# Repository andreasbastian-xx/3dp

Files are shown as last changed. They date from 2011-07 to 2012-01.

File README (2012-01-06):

arduino/ contains firmware for the 3D printer.

autoCAD/ contains a variety of 3D models.

Datasheets and ref/ contains several datasheets and reference material for parts used in the project.

Final Report/ contains the final report that I wrote about the project.

test_files/ contains GCode generated by replicatorG and .stl models.

This project was funded by the Halpern Family Engineering Design Fund during the summer of 2011 at the Swarthmore College Department of Engineering.  

Please feel free to download and use any files or code from this project, though the modified firmware is highly customized.  Also, please feel free to contact me with questions or for any other reason at andy(at)andreasbastian.com.

Andreas Bastian 2012

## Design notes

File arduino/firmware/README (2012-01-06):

in_use/ contains the successfully modified Ultimaker Arduino firmware.

old_code/ contains abandoned and dissected firmware files that I used to probe and explore the firmware.  

Andreas Bastian 2012

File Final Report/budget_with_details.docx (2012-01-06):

Item: | Cost: | Use in the Project:
Aluminum angle stock | $30 | Used in a machined bracket to join two flatbed scanners to build a 2D translation system. This prototype translation system was abandoned for a simpler and more reliable system.
Steel drill rod | $15 | Used as gantry material in both prototype translation systems.
Linear bearings | $120 | Intended for use in the first prototype translation system and were not used in the second prototype translation system.
Stepper drivers | $100 | Five A4983 stepper drivers were purchased to supply power to the various stepper motors that actuate the hardware.
Arduino Microcontroller | $64 | Used to control all motors and sensors in the system and manage communication with the computer.
Photointerrupters | $15 | Used to check positioning of the 2D translation system.
Lasers | $198 | Two fiber-coupled infrared lasers were purchased used.
Brake cable | $15 | The cable was used to actuate the laser shuttering mechanism.
MDF | $10 | Chief construction material of the prototype system.
5kgs Candelilla wax powder | $95 | Main component of the print powder.
Sieves | $110 | Used for mixing, refining, and reclaiming the print powder.
Total Project Cost: | $772 | All materials purchased for the project.
Total Prototype Cost: | $413 | Materials used in the final prototype system.

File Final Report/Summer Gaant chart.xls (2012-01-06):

Tasks | 5/29 - 6/4 | 6/5 - 6/11 | 6/12 - 6/18 | 6/18 - 6/25 | 6/26 - 7/2 | 7/3 - 7/9 | 7/10 - 7/16 | 7/17 - 7/23 | 7/24 - 7/30 | 7/31 - 8/6
1). X-Y Translation System
a). Research, design, and purchase materials
b). Fabrication
2). Laser Optics
a). Research and design mounts and optics options
b). Install laser and optics on X-Y translator
c). Laser characterization studies
3). Powder Bed and Reservoir
a). Research, design, and purchase materials
b). Fabricate and test
4). Powder Distributor
a). Research, design, and purchase materials
b). Fabricate and install on powder bed
5). Software
a). Write and distribute software design survey
b). Work on user interface

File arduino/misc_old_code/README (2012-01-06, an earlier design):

This directory contains a variety of small programs used in testing and calibration as well as abandoned DIY serial communication code.

Andreas Bastian 2012

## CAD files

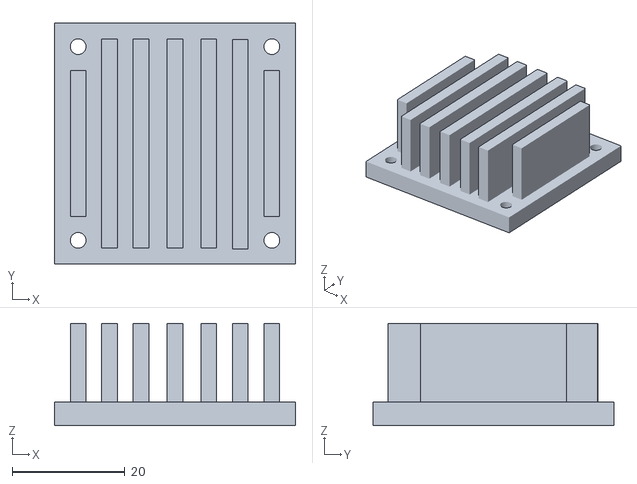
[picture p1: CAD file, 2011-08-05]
autoCAD models/stepper_heatsink_single.stl
42.7 x 42.7 x 18.2

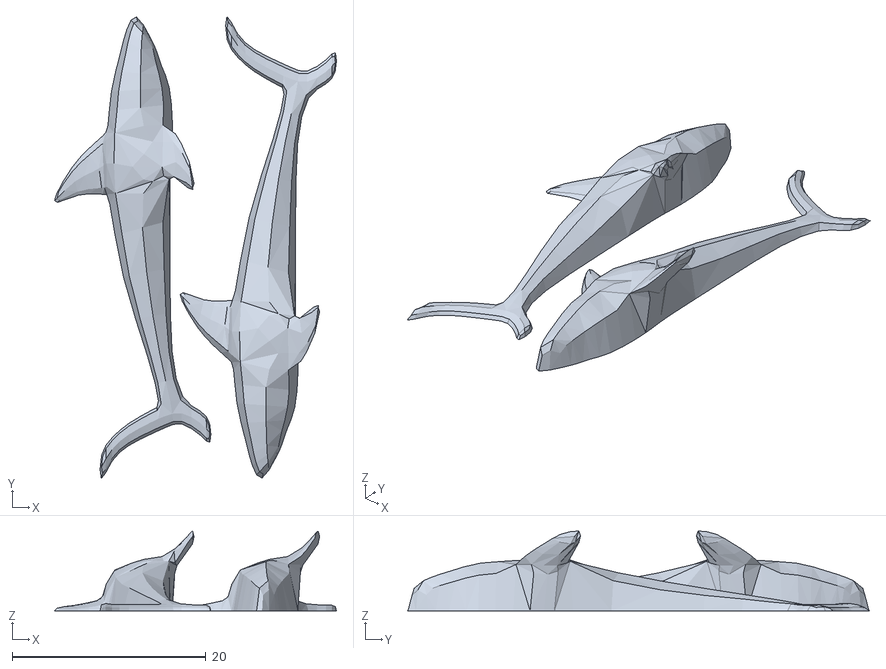
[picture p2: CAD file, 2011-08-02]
test_files/2-3inch_shark.stl
29.1 x 47.7 x 8.24

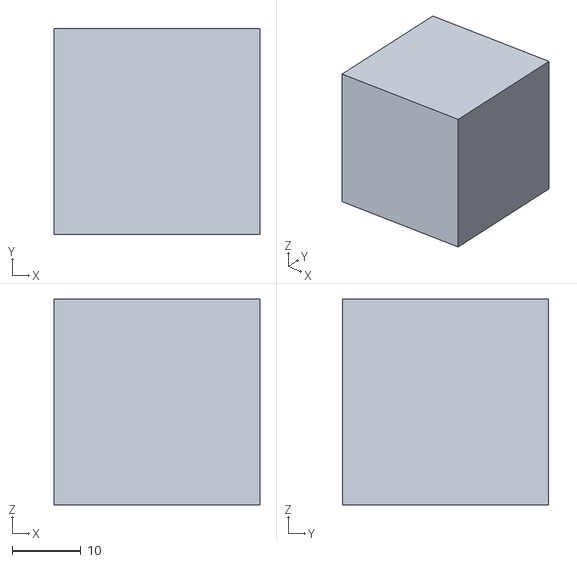
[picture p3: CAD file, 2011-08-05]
test_files/thingiverse/40mmcube.stl
30.0 x 30.0 x 30.0

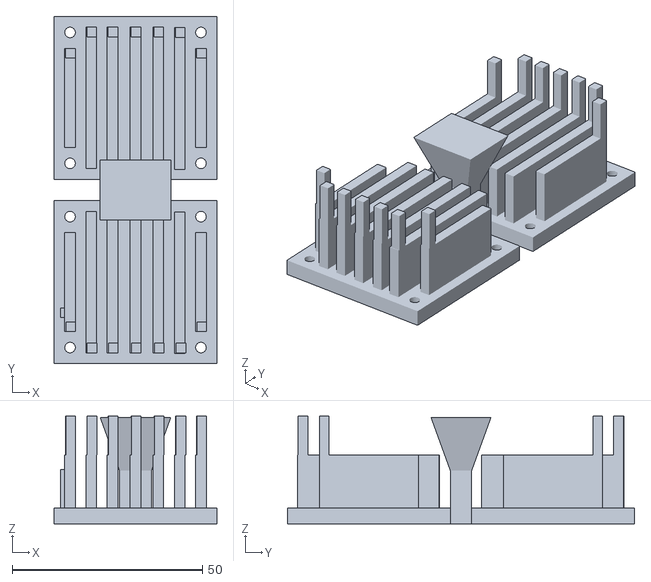
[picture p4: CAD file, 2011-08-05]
autoCAD models/stepper_heatsink.stl
42.7 x 91.1 x 28.3

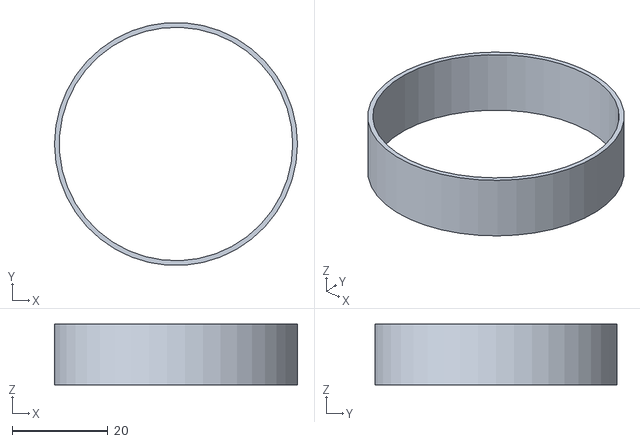
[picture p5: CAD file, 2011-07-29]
test_files/2_inch_circle_scaled.stl
50.8 x 50.7 x 12.7

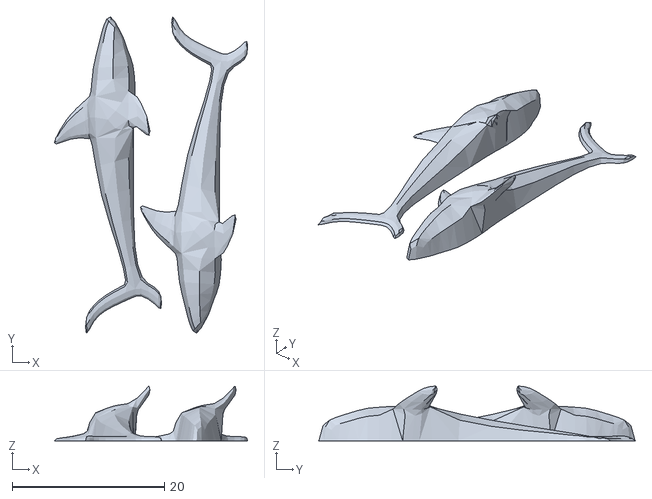
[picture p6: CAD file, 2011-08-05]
test_files/thingiverse/shark-l-r.stl
25.4 x 41.7 x 7.20

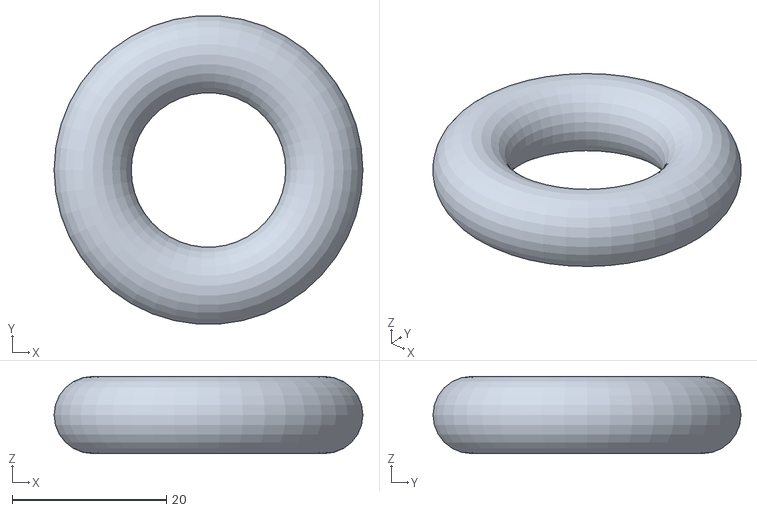
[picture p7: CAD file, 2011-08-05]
autoCAD models/torus.stl
40.0 x 39.9 x 10.00

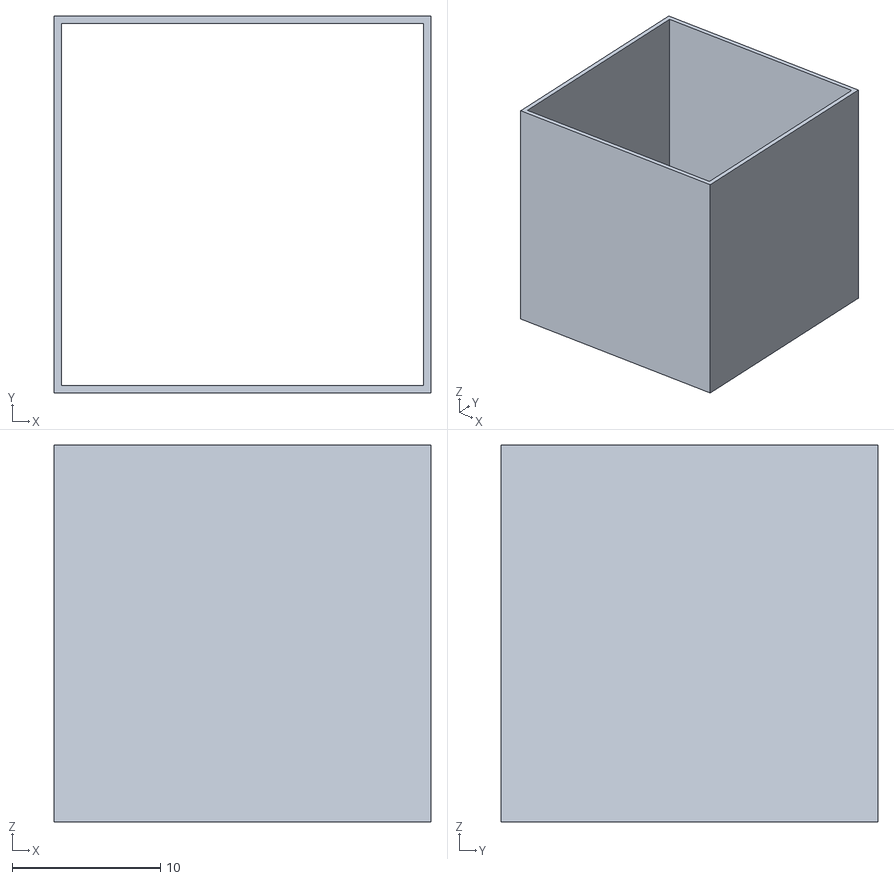
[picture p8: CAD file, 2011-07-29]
test_files/square_tube_fresh.stl
25.4 x 25.4 x 25.4

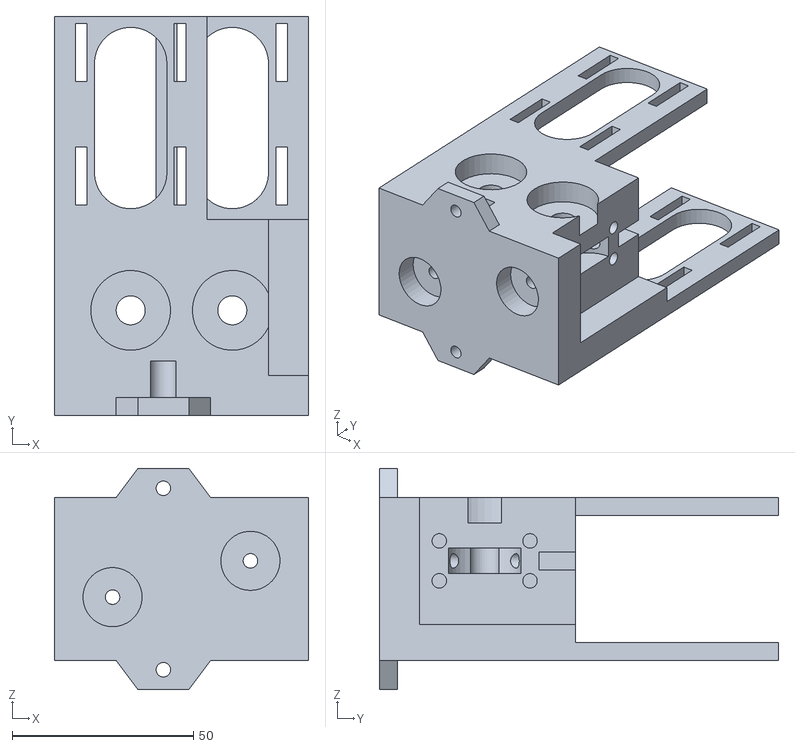
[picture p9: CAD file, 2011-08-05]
test_files/thingiverse/dualextruder.STL
70.0 x 110.0 x 61.0

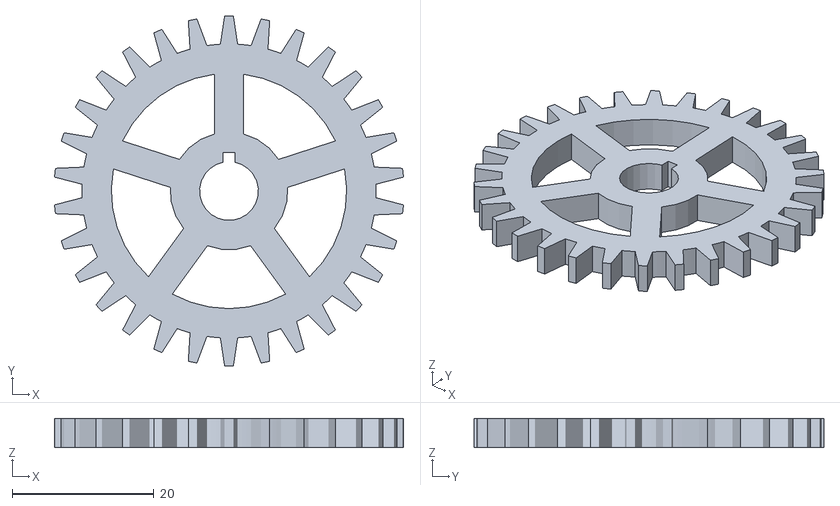
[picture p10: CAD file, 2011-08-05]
autoCAD models/gear.stl
49.2 x 49.4 x 4.15

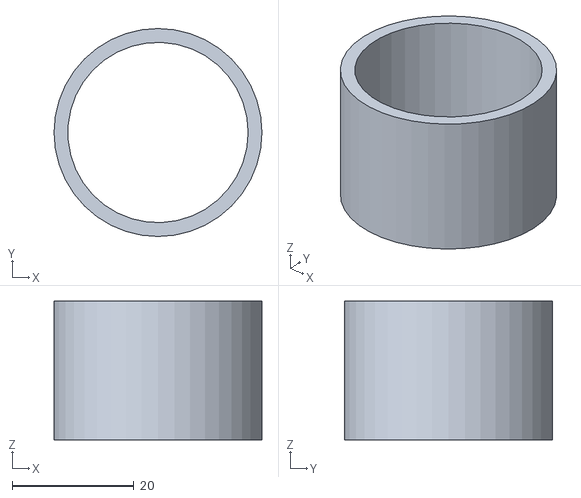
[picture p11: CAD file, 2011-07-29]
test_files/pipe_gcode_raw.stl
34.2 x 34.2 x 22.8

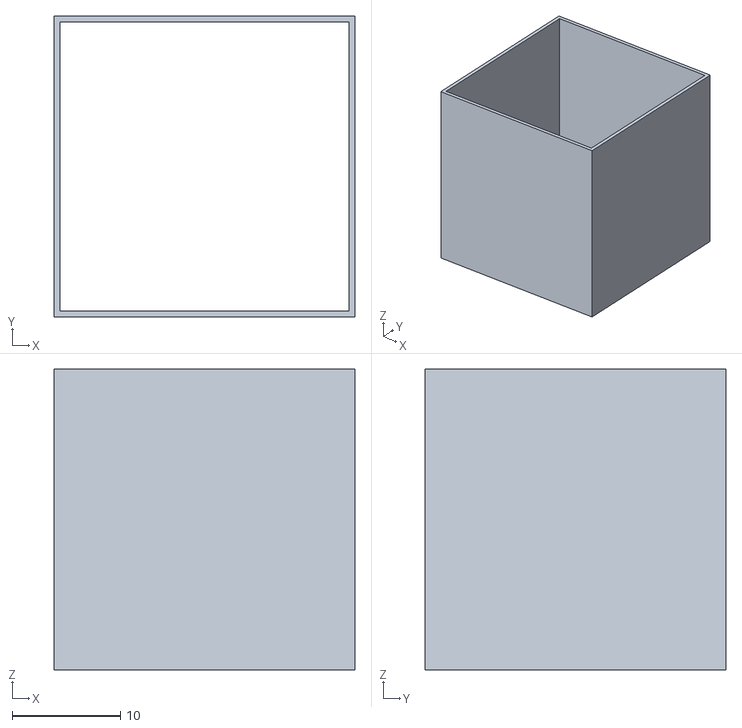
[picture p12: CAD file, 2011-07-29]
test_files/square_pipe.stl
27.8 x 27.8 x 27.8

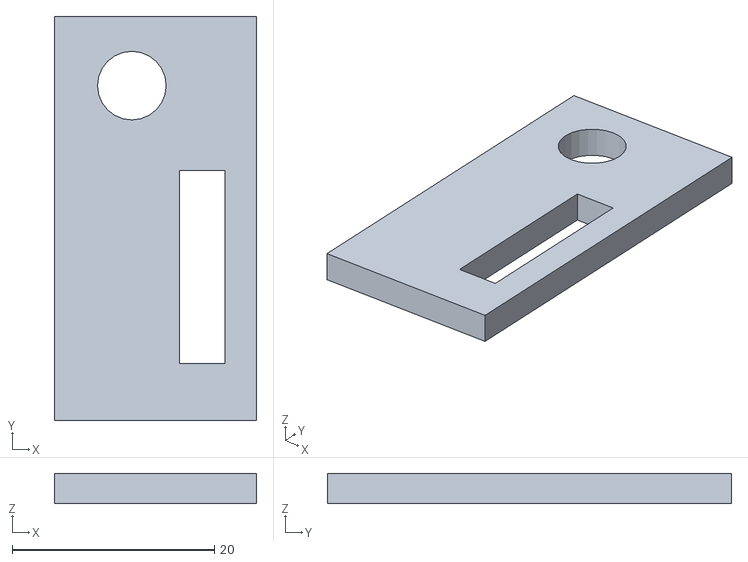
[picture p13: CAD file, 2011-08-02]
autoCAD models/test_block.stl
20.0 x 40.0 x 3.00

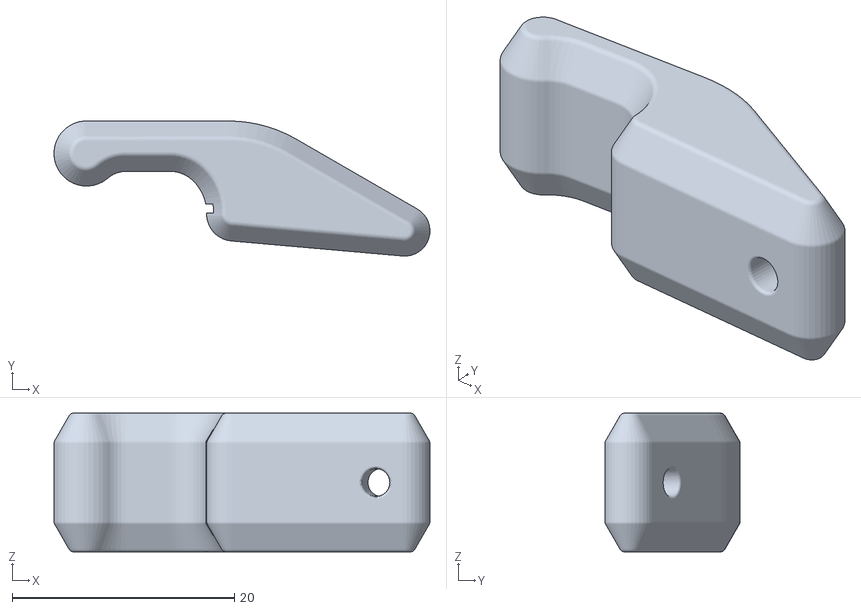
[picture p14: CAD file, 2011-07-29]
test_files/test.stl
33.8 x 12.1 x 12.5

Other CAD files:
autoCAD models/trig_geo_piece.dwg
autoCAD models/1x40x0.5_bar.stl
autoCAD models/2_inch_circle.dwg
autoCAD models/gear.dwg
autoCAD models/stepper_heatsink.dwg
autoCAD models/test_block.dwg
autoCAD models/torus.dwg
test_files/1mmSquare.stl
test_files/pipe.stl

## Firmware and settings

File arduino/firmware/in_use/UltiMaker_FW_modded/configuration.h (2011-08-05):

#ifndef CONFIGURATION_H
#define CONFIGURATION_H

#define VERSION_STRING "ULTIMAKER:BATCH=1,PCB=1.5.3,ATMEGA=2560 FW:V=1.1,BUILD=1 E0:TC597=1,SPEED=14 Z:PITCH=3MM"

/*
 *  This is the configuration file for the RepRap Motherboard microcontroller.
 *  Set values in it to match your RepRap machine.
 *  
 *  Lines in here with a 
 *
 *        // *RO
 *
 *  Comment at the end (read-only) should probably only be changed if you really
 *  know what you are doing...
 */

// Here are the Motherboard codes; set MOTHERBOARD to the right one
// A standard Mendel is MOTHERBOARD 2

// (Arduino: 0 - no longer in use)
// Sanguino or RepRap Motherboard with direct drive extruders: 1
// RepRap Motherboard with RS485 extruders: 2
// Arduino Mega: 3
// Ultimaker users: This should be 3 if your system uses an Arduino Mega, not 1.1 or something that you see on your Ultimaker Electronics.

#define MOTHERBOARD 3 

/*********************************************************************************************
*  _   _ _ _   _                 _
* | | | | | |_(_)_ __ ___   __ _| | _____ _ __
* | | | | | __| | '_ ` _ \ / _` | |/ / _ \ '__|
* | |_| | | |_| | | | | | | (_| |   <  __/ |
*  \___/|_|\__|_|_| |_| |_|\__,_|_|\_\___|_|
* 
* Valid for versions: 1.0 and 1.1
* For documentation, see http://www.ultimaker.com/
*********************************************************************************************/

#if MOTHERBOARD == 3

// Set to 1 if enable pins are inverting
// For RepRap stepper boards version 1.x the enable pins are *not* inverting.
// For RepRap stepper boards version 2.x and above the enable pins are inverting.
#define INVERT_ENABLE_PINS 1

// Set ENDSTOP_PULL_UPS to "true" if you're using microswitches
// This will put a logical high in the input pins by connecting an internal 20K resistor to Vcc.
#define ENDSTOP_PULL_UPS true

// Set to one if the axis opto-sensor outputs inverting (ie: 1 means open, 0 means closed)
// RepRap opto endstops with H21LOI sensors are not inverting; ones with H21LOB
// are inverting.
// Set [XYZ]_ENDSTOP_INVERTING to "true" for using microswitches.

#define X_ENDSTOP_INVERTING true
#define Y_ENDSTOP_INVERTING true
#define Z_ENDSTOP_INVERTING true
#define THRESH 60 //logic threshold for analogRead(LIM_PIN)

// Motherboard 3 driving Pololu microstepping controllers - 16 microsteps

// Axis scaling in stepper-motor steps per mm of movement

// Select 1/16 STEP!
#define X_STEPS_PER_MM   12.322
#define INVERT_X_DIR 0

// Select 1/16 STEP!
#define Y_STEPS_PER_MM   12.424
#define INVERT_Y_DIR 0

// This stepper driver should be in EIGHT STEP MODE (LOW/HIGH/LOW)
#define Z_STEPS_PER_MM   191.86
#define INVERT_Z_DIR 0

//Feed Piston:
#define F_STEPS_PER_MM   91.134
#define INVERT_F_DIR 1

//Wiper stepper:
#define W_STEPS_PER_MM   9.6189 
#define INVERT_Z_DIR 0

// Stepper-driven extruder
// E_STEPS_PER_MM is the number of steps needed to 
// extrude 1mm out of the nozzle.  E0 for extruder 0;
// E1 for extruder 1, and so on.

//#define E0_STEPS_PER_MM   14.0//17.6      // NEMA 17 59/11 geared extruder 8mm diameter drive
//#define E1_STEPS_PER_MM   14.0//17.6      // NEMA 17 59/11 geared extruder 8mm diameter drive

// The temperature routines get called each time the main loop
// has gone round this many times

#define SLOW_CLOCK 2000

// If you want to enable fancy stuff like RGB LEDs for feedback and just to show off.
// Make sure FANCY is defined if you want to have this enabled, otherwise comment it out.
//#define FANCY
//#define FANCY_LCD
// Here you can choose 0.0-1.0 for the power to the LED array.
//#define FANCY_LED_PWM_MULTIPLY 1.0 // in case you run everything at a voltage higher than 12V!

#endif

//**********************************************************************************************

// The speed at which to talk with the host computer; default is 57600

#define HOST_BAUD 57600 // *RO

// Set 1s where you have endstops; 0s where you don't
// Both Darwin and Mendel have MIN endstops, but not MAX ones.

#define ENDSTOPS_MIN_ENABLED 1
#define ENDSTOPS_MAX_ENABLED 1

// The number of mm below which distances are insignificant (one tenth the
// resolution of the machine is the default value).

#define SMALL_DISTANCE 0.01 // *RO

// Useful to have its square

#define SMALL_DISTANCE2 (SMALL_DISTANCE*SMALL_DISTANCE) // *RO

//our maximum feedrates in mm/minute
#define FAST_XY_FEEDRATE 800.0
#define FAST_Z_FEEDRATE  100

// Data for acceleration calculations
// Comment out the next line to turn accelerations off
//#define ACCELERATION_ON
// ERIK: changing to a software configurable parameter:
// To enable acceleration by default, configure to true. It can be turned of with M-code M142
//acceleration_enabled = true;

#define SLOW_XY_FEEDRATE 360 // Speed from which to start accelerating
#define SLOW_Z_FEEDRATE 40

#define W_FEEDRATE 800 //wiper feedrate


#if INVERT_ENABLE_PINS == 1  // *RO
#define ENABLE_ON LOW        // *RO
#else                        // *RO
#define ENABLE_ON HIGH       // *RO
#endif                       // *RO

// Set these to 1 to disable an axis when it's not being used,
// and for the extruder.  Usually only Z is disabled when not in
// use.  You will probably find that disabling the others (i.e.
// powering down the steppers that drive them) when the ends of
// movements are reached causes poor-quality builds.  (Inertia
// causes overshoot if the motors are not left powered up.)

#define DISABLE_X 0
#define DISABLE_Y 0
#define DISABLE_Z 0
#define DISABLE_E 0

// The number of 5-second intervals to wait at the target temperature for things to stabilise.
// Too short, and the extruder will jam as only part of it will be hot enough.
// Too long and the melt will extend too far up the insulating tube.
// Default value: 10

//#define WAIT_AT_TEMPERATURE 10

// PID gains.  E_ = extruder, B_ = bed.  The Es are about right for a brass extruder about 8 mm 
// in diameter and 30 mm long heated by a 6 ohm coil with a 12v supply.  The B_ values are OK
// for the bed described here:  http://reprap.org/wiki/Mendel_heated_bed
// Extruding increase biases the input to the extruder heater when the extruder
// is running as it requires more power.

//#define E_TEMP_PID_PGAIN 5.5// HIGHER: quicker 
//#define E_TEMP_PID_IGAIN 0.50 // HIGHER: makes overshoot bigger, but also shorter if you LIMIT it, see below)
//#define E_TEMP_PID_DGAIN 0.2 // Not doing much good
//#define E_TEMP_PID_BAND 0.0
//// To prevent integral windup, allow the I*GAIN to only have this much influence (below 255 makes sense):
//#define E_TEMP_PID_I_LIMIT 60/E_TEMP_PID_IGAIN
//#define EXTRUDING_INCREASE 7
//
//#define B_TEMP_PID_PGAIN 2
//#define B_TEMP_PID_IGAIN 0.07
//#define B_TEMP_PID_DGAIN 1
//#define B_TEMP_PID_BAND 1000.0

// To turn on PID debugging strings, set this to EXTRUDER_0_HEATER_PIN, EXTRUDER_1_HEATER_PIN or BED_HEATER_PIN
//#define DEBUG_PID EXTRUDER_0_HEATER_PIN

// The width of Henry VIII's thumb (or something).

#define INCHES_TO_MM 25.4 // *RO

// The things below should not be changed unless you know what you're doing:

#define X_STEPS_PER_INCH (X_STEPS_PER_MM*INCHES_TO_MM) // *RO
#define Y_STEPS_PER_INCH (Y_STEPS_PER_MM*INCHES_TO_MM) // *RO
#define Z_STEPS_PER_INCH (Z_STEPS_PER_MM*INCHES_TO_MM) // *RO
#define F_STEPS_PER_INCH (F_STEPS_PER_MM*INCHES_TO_MM) // *RO
#define W_STEPS_PER_INCH (W_STEPS_PER_MM*INCHES_TO_MM) // *RO


//our command string length

#define COMMAND_SIZE 128 // *RO

// Our response string length

#define RESPONSE_SIZE 256 // *RO

// The size of the movement buffer

#define BUFFER_SIZE 4 // *RO

// Number of microseconds between timer interrupts when no movement
// is happening

#define DEFAULT_TICK (long)1000 // *RO

// What delay() value to use when waiting for things to free up in milliseconds

#define WAITING_DELAY 1 // *RO

///******************************************************************************

// You probably only want to edit things below this line if you really really
// know what you are doing...


void delayMicrosecondsInterruptible(unsigned int us);

// Inline interrupt control functions

inline void enableTimerInterrupt() 
{
   TIMSK1 |= (1<<OCIE1A);
}
	
inline void disableTimerInterrupt() 
{
     TIMSK1 &= ~(1<<OCIE1A);
}
        
inline void setTimerCeiling(unsigned int c) 
{
    OCR1A = c;
}

inline void resetTimer()
{
  TCNT2 = 0;
}

#endif

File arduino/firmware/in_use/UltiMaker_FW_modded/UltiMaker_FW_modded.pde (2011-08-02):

#include <ctype.h>
#include <stdio.h>
#include "WProgram.h"
#include <HardwareSerial.h>
#include <avr/pgmspace.h>
#include "vectors.h"
#include "configuration.h"
#include "hostcom.h"
#include "intercom.h"
#include "pins.h"
#include "cartesian_dda.h"
/** ULTIMAKER EDITION
 * 
 * RepRap GCode interpreter.
 * 
 * IMPORTANT
 * 
 * Before changing this interpreter, read this page:
 * 
 * http://objects.reprap.org/wiki/Mendel_User_Manual:_RepRapGCodes
 * 
 */


// Sanguino G-code Interpreter
// Arduino v1.0 by Mike Ellery - initial software (mellery@gmail.com)
// v1.1 by Zach Hoeken - cleaned up and did lots of tweaks (hoeken@gmail.com)
// v1.2 by Chris Meighan - cleanup / G2&G3 support (cmeighan@gmail.com)
// v1.3 by Zach Hoeken - added thermocouple support and multi-sample temp readings. (hoeken@gmail.com)
// Sanguino v1.4 by Adrian Bowyer - added the Sanguino; extensive mods... (a.bowyer@bath.ac.uk)
// Sanguino v1.5 by Adrian Bowyer - implemented 4D Bressenham XYZ+ stepper control... (a.bowyer@bath.ac.uk)
// Sanguino v1.6 by Adrian Bowyer - implemented RS485 extruders
// Arduino Mega v1.7 by Adrian Bowyer


float e_prev = 0;
float z_prev = 0;

static hostcom talkToHost;

// Each entry in the buffer is an instance of cartesian_dda.

cartesian_dda* cdda[BUFFER_SIZE];

static cartesian_dda cdda0;
static cartesian_dda cdda1;
static cartesian_dda cdda2;
static cartesian_dda cdda3;

volatile byte head;
volatile byte tail;
bool led;

word interruptBlink;

// Where the machine is from the point of view of the command stream

FloatPoint where_i_am;

// Our interrupt function

/*
This has an internal flag (nonest) to prevent its being interrupted by another timer interrupt.
 It re-enables interrupts internally (not something that one would normally do with an ISR).
 This allows USART interrupts to be serviced while this ISR is also live, and so prevents 
 communications errors.
 */




volatile bool nonest;

ISR(TIMER1_COMPA_vect)
{
  if(nonest)
    return;
  nonest = true;
  sei();
  interruptBlink++;
  if(interruptBlink == 0x280)
  {
    blink();
    interruptBlink = 0; 
  }


  if(cdda[tail]->active())
    cdda[tail]->dda_step();
  else
    dQMove();
  nonest = false;
}


void setup()
{
  pinMode(13, OUTPUT);
  pinMode(W_ENABLE_PIN, OUTPUT);
  pinMode(LASER_PIN, OUTPUT);
  pinMode(Z_STEP_PIN, OUTPUT);
  pinMode(F_STEP_PIN, OUTPUT);  
  pinMode(W_STEP_PIN, OUTPUT);

  pinMode(W_DIR_PIN, OUTPUT);

  nonest = false;
  disableTimerInterrupt();
  setupTimerInterrupt();
  interruptBlink = 0;
  pinMode(DEBUG_PIN, OUTPUT);
  led = false;

  setupGcodeProcessor();

  head = 0;
  tail = 0;

  cdda[0] = &cdda0;
  cdda[1] = &cdda1;  
  cdda[2] = &cdda2;  
  cdda[3] = &cdda3;

  for(byte i = 0; i < 4; i++)
    cdda[i]->set_units(true);

  //setExtruder();

  init_process_string();

  talkToHost.start();

  setTimer(DEFAULT_TICK);
  enableTimerInterrupt();


}

// This does a hard stop.  It disables interrupts, turns off all the motors 
// (regardless of DISABLE_X etc), and calls extruder.shutdown() for each
// extruder.  It then spins in an endless loop, never returning.  The only
// way out is to press the reset button.

void shutdown()
{
  // No more stepping or other interrupts
  cli();
  // Delete everything in the ring buffer
  cancelAndClearQueue();
  // Motors off

#if MOTHERBOARD > 0  
  digitalWrite(X_ENABLE_PIN, !ENABLE_ON);
  digitalWrite(Y_ENABLE_PIN, !ENABLE_ON);
  digitalWrite(Z_ENABLE_PIN, !ENABLE_ON);
  digitalWrite(F_ENABLE_PIN, !ENABLE_ON);
  digitalWrite(W_ENABLE_PIN, !ENABLE_ON);
  digitalWrite(LASER_PIN, HIGH);//turn off laser
#endif

#if MOTHERBOARD != 2

#endif

  //  int a=50;
  //  while(a--) {blink(); delay(50);}

  // LED off

  digitalWrite(DEBUG_PIN, 0);


  // Till the end of time...

  for(;;); 
}

void loop()
{
  nonest = false;
  get_and_do_command(); 
}

//******************************************************************************************

// The move buffer

inline void cancelAndClearQueue()
{
  tail = head;	// clear buffer
  for(int i=0;i<BUFFER_SIZE;i++)
    cdda[i]->shutdown();
}

inline bool qFull()
{
  if(tail == 0)
    return head == (BUFFER_SIZE - 1);
  else
    return head == (tail - 1);
}

inline bool qEmpty()
{
  return tail == head && !cdda[tail]->active();
}

inline void qMove(const FloatPoint& p)
{
  while(qFull()) delay(WAITING_DELAY);
  byte h = head; 
  h++;
  if(h >= BUFFER_SIZE)
    h = 0;
  cdda[h]->set_target(p);
  head = h;
}

inline void dQMove()
{
  if(qEmpty())
    return;
  byte t = tail;  
  t++;
  if(t >= BUFFER_SIZE)
    t = 0;
  cdda[t]->dda_start();
  tail = t; 
}

inline void setUnits(bool u)
{
  for(byte i = 0; i < BUFFER_SIZE; i++)
    cdda[i]->set_units(u); 
}


inline void setPosition(const FloatPoint& p)
{
  where_i_am = p;  
}

void blink()
{
  led = !led;
  if(led)
    digitalWrite(DEBUG_PIN, 1);
  else
    digitalWrite(DEBUG_PIN, 0);
} 


//******************************************************************************************

// Interrupt functions

void setupTimerInterrupt()
{
  //clear the registers
  TCCR1A = 0;
  TCCR1B = 0;
  TCCR1C = 0;
  TIMSK1 = 0;

  //waveform generation = 0100 = CTC
  TCCR1B &= ~(1<<WGM13);
  TCCR1B |=  (1<<WGM12);
  TCCR1A &= ~(1<<WGM11); 
  TCCR1A &= ~(1<<WGM10);

  //output mode = 00 (disconnected)
  TCCR1A &= ~(1<<COM1A1); 
  TCCR1A &= ~(1<<COM1A0);
  TCCR1A &= ~(1<<COM1B1); 
  TCCR1A &= ~(1<<COM1B0);

  //start off with a slow frequency.
  setTimerResolution(4);
  setTimerCeiling(65535);
}

void setTimerResolution(byte r)
{
  //here's how you figure out the tick size:
  // 1000000 / ((16000000 / prescaler))
  // 1000000 = microseconds in 1 second
  // 16000000 = cycles in 1 second
  // prescaler = your prescaler

    // no prescaler == 0.0625 usec tick
  if (r == 0)
  {
    // 001 = clk/1
    TCCR1B &= ~(1<<CS12);
    TCCR1B &= ~(1<<CS11);
    TCCR1B |=  (1<<CS10);
  }	
  // prescale of /8 == 0.5 usec tick
  else if (r == 1)
  {
    // 010 = clk/8
    TCCR1B &= ~(1<<CS12);
    TCCR1B |=  (1<<CS11);
    TCCR1B &= ~(1<<CS10);
  }
  // prescale of /64 == 4 usec tick
  else if (r == 2)
  {
    // 011 = clk/64
    TCCR1B &= ~(1<<CS12);
    TCCR1B |=  (1<<CS11);
    TCCR1B |=  (1<<CS10);
  }
  // prescale of /256 == 16 usec tick
  else if (r == 3)
  {
    // 100 = clk/256
    TCCR1B |=  (1<<CS12);
    TCCR1B &= ~(1<<CS11);
    TCCR1B &= ~(1<<CS10);
  }
  // prescale of /1024 == 64 usec tick
  else
  {
    // 101 = clk/1024
    TCCR1B |=  (1<<CS12);
    TCCR1B &= ~(1<<CS11);
    TCCR1B |=  (1<<CS10);
  }
}

unsigned int getTimerCeiling(const long& delay)
{
  // our slowest speed at our highest resolution ( (2^16-1) * 0.0625 usecs = 4095 usecs)
  if (delay <= 65535L)
    return (delay & 0xffff);
  // our slowest speed at our next highest resolution ( (2^16-1) * 0.5 usecs = 32767 usecs)
  else if (delay <= 524280L)
    return ((delay / 8) & 0xffff);
  // our slowest speed at our medium resolution ( (2^16-1) * 4 usecs = 262140 usecs)
  else if (delay <= 4194240L)
    return ((delay / 64) & 0xffff);
  // our slowest speed at our medium-low resolution ( (2^16-1) * 16 usecs = 1048560 usecs)
  else if (delay <= 16776960L)
    return ((delay / 256) & 0xffff);
  // our slowest speed at our lowest resolution ((2^16-1) * 64 usecs = 4194240 usecs)
  else if (delay <= 67107840L)
    return ((delay / 1024) & 0xffff);
  //its really slow... hopefully we can just get by with super slow.
  else
    return 65535;
}

byte getTimerResolution(const long& delay)
{
  // these also represent frequency: 1000000 / delay / 2 = frequency in hz.

  // our slowest speed at our highest resolution ( (2^16-1) * 0.0625 usecs = 4095 usecs (4 millisecond max))
  // range: 8Mhz max - 122hz min
  if (delay <= 65535L)
    return 0;
  // our slowest speed at our next highest resolution ( (2^16-1) * 0.5 usecs = 32767 usecs (32 millisecond max))
  // range:1Mhz max - 15.26hz min
  else if (delay <= 524280L)
    return 1;
  // our slowest speed at our medium resolution ( (2^16-1) * 4 usecs = 262140 usecs (0.26 seconds max))
  // range: 125Khz max - 1.9hz min
  else if (delay <= 4194240L)
    return 2;
  // our slowest speed at our medium-low resolution ( (2^16-1) * 16 usecs = 1048560 usecs (1.04 seconds max))
  // range: 31.25Khz max - 0.475hz min
  else if (delay <= 16776960L)
    return 3;
  // our slowest speed at our lowest resolution ((2^16-1) * 64 usecs = 4194240 usecs (4.19 seconds max))
  // range: 7.812Khz max - 0.119hz min
  else if (delay <= 67107840L)
    return 4;
  //its really slow... hopefully we can just get by with super slow.
  else
    return 4;
}


// Depending on how much work the interrupt function has to do, this is
// pretty accurate between 10 us and 0.1 s.  At fast speeds, the time
// taken in the interrupt function becomes significant, of course.

// Note - it is up to the user to call enableTimerInterrupt() after a call
// to this function.

inline void setTimer(long delay)
{
  // delay is the delay between steps in microsecond ticks.
  //
  // we break it into 5 different resolutions based on the delay. 
  // then we set the resolution based on the size of the delay.
  // we also then calculate the timer ceiling required. (ie what the counter counts to)
  // the result is the timer counts up to the appropriate time and then fires an interrupt.

  // Actual ticks are 0.0625 us, so multiply delay by 16

  delay <<= 4;

  setTimerCeiling(getTimerCeiling(delay));
  setTimerResolution(getTimerResolution(delay));
}


void delayMicrosecondsInterruptible(unsigned int us)
{
  // for a one-microsecond delay, simply return.  the overhead
  // of the function call yields a delay of approximately 1 1/8 us.
  if (--us == 0)
    return;

  // the following loop takes a quarter of a microsecond (4 cycles)
  // per iteration, so execute it four times for each microsecond of
  // delay requested.
  us <<= 2;

  // account for the time taken in the preceeding commands.
  us -= 2;

  // busy wait
  __asm__ __volatile__ ("1: sbiw %0,1" "\n\t" // 2 cycles
"brne 1b" : 
  "=w" (us) : 
  "0" (us) // 2 cycles
    );
}

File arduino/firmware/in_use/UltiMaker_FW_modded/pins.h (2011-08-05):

#ifndef PINS_H
#define PINS_H

#define MOTHERBOARD 3

// Set this to 0, 1, x for board versions v1.0, v1.1 or v1.x, etc.
#define ULTIMAKER_BOARD_MINOR_VERSION 5

#if MOTHERBOARD == 3

#ifndef __AVR_ATmega1280__
#ifndef __AVR_ATmega2560__
#error Oops!  Make sure you have 'Arduino Mega' selected from the 'Tools -> Boards' menu.
#endif
#endif

/*********************************************************************************************
*  _   _ _ _   _                 _
* | | | | | |_(_)_ __ ___   __ _| | _____ _ __
* | | | | | __| | '_ ` _ \ / _` | |/ / _ \ '__|
* | |_| | | |_| | | | | | | (_| |   <  __/ |
*  \___/|_|\__|_|_| |_| |_|\__,_|_|\_\___|_|
* 
* Valid for versions: 1.0 and 1.1
* For documentation, see http://www.ultimaker.com/
*
* NOTE: Configure ULTIMAKER_BOARD to the version you have!
* 
*********************************************************************************************/

// SELECT THE VERSION OF THE MOTHERBOARD THAT YOU HAVE.
#if ULTIMAKER_BOARD_MINOR_VERSION == 5

#define DEBUG_PIN        50

#define X_STEP_PIN (byte)2
#define X_DIR_PIN (byte)3
#define X_MIN_PIN A0//(byte)4
#define X_MAX_PIN A1//(byte)5
#define X_ENABLE_PIN (byte)6

#define Y_STEP_PIN (byte)7
#define Y_DIR_PIN (byte)8
#define Y_MIN_PIN A2//(byte)9
#define Y_MAX_PIN A3//(byte)10
#define Y_ENABLE_PIN (byte)11

#define Z_STEP_PIN (byte)22 
#define Z_DIR_PIN (byte)23
#define Z_MIN_PIN (byte)24
#define Z_MAX_PIN (byte)25
#define Z_ENABLE_PIN (byte)26

#define F_STEP_PIN (byte)27 
#define F_DIR_PIN (byte)28
#define F_MIN_PIN (byte)29
#define F_MAX_PIN (byte)30
#define F_ENABLE_PIN (byte)31

#define W_STEP_PIN (byte)32
#define W_DIR_PIN (byte)33
#define W_MIN_PIN (byte)34
#define W_MAX_PIN (byte)35
#define W_ENABLE_PIN (byte)36

#define LASER_PIN (byte)12



#endif //ULTIMAKER_BOARD=="1.5.3"


#else
#error Unknown MOTHERBOARD value in configuration.h

#endif

#endif

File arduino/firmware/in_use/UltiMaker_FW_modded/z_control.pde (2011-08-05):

//functions for controlling the motion of the powder management hardware and 
//z-axis

void doZ(float layerThickness)
{
  //enable motors here
  digitalWrite(W_ENABLE_PIN, HIGH);
  digitalWrite(F_ENABLE_PIN, HIGH);
  digitalWrite(Z_ENABLE_PIN, HIGH);
  delay(2);//wait for driver to wake up

  //  digitalWrite(Z_ENABLE_PIN, HIGH);
  //  digitalWrite(F_ENABLE_PIN, HIGH);
  //  digitalWrite(W_ENABLE_PIN, HIGH);

  //just use this func for printing, so only moving in one direction
  int steps = Z_STEPS_PER_MM*layerThickness;
  float milDel = 0;
  long feedDelay = (layerThickness * 60000000.0) / (SLOW_Z_FEEDRATE*steps);
  //move z-Axis
  if (feedDelay >= 16383)
    milDel = feedDelay / 1000;
  else
    milDel = 0;
  digitalWrite(Z_DIR_PIN, HIGH);
  for(int i = 0; i < steps; i++)
  {
    takeStep(Z_STEP_PIN);
    if (milDel > 0)
      delay(milDel);			
    else
      delayMicroseconds(feedDelay);
  }

  //move feed piston:
  steps = F_STEPS_PER_MM*layerThickness*1.1;//scale up by 10% to account for powder loses
  
  for(int i = 0; i < steps; i++)
  {
    takeStep(F_STEP_PIN);
    if (milDel > 0)
      delay(milDel);			
    else
      delayMicroseconds(feedDelay);
  }

  //finally, distribute the powder with the wiper:
  steps = 11*25.4*W_STEPS_PER_MM;
  feedDelay = (11*25.4*60000000.0) / (W_FEEDRATE*steps);
  if (feedDelay >= 16383)
    milDel = feedDelay / 1000;
  else
    milDel = 0;
  digitalWrite(W_DIR_PIN,HIGH);
  for(int i = 0; i < 500; i++)
  {
    takeStep(W_STEP_PIN);
    if (milDel > 0)
      delay(milDel);			
    else
      delayMicroseconds(feedDelay);
  }



  digitalWrite(W_DIR_PIN,LOW);
  for(int i = 0; i < 500; i++)
  {
    takeStep(W_STEP_PIN);
    if (milDel > 0)
      delay(milDel);			
    else
      delayMicroseconds(feedDelay);
  }



  //disable motors here
  digitalWrite(W_ENABLE_PIN, LOW);
  digitalWrite(F_ENABLE_PIN, LOW);
  digitalWrite(Z_ENABLE_PIN, LOW);

}

void laserOn()
{
  digitalWrite(LASER_PIN, LOW);
}

void laserOff()
{
  digitalWrite(LASER_PIN, HIGH);
}

void takeStep(int sp)
{
  digitalWrite(sp, HIGH);
  digitalWrite(sp, LOW);
}

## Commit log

2011-07-28 first commit of all arduino code, including mostly functional firmware (UltiMaker version)
    [configuration.h]
2011-07-29 still need to fix that sneaky x-direction bug in arduino fw
    [1_inch_square_tube.stl, 1mmSquare.stl, 2_inch_circle.dwg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]
2011-07-31 including UM_FW_experimentation
    [1x40x0.5_bar.stl, 2_inch_circle.stl, configuration.h]
2011-07-31 a couple of problems in FW to fix: laser control and doZ() timing
2011-08-02 added more autocad models and a model of parrish
    [2-3inch_shark.stl, configuration.h, gear.dwg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]
2011-08-05 final push of the summer-- functional code, thingiverse files, and some more datasheets
    [40mmcube.stl, configuration.h, dualextruder.STL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]
2012-01-06 I cleaned up and reoganized the directories, making things a little more accessible.
    [Summer Gaant chart.xls, configuration.h]
2012-02-04 rejiggered directory structure
    [configuration.h, shark-l-r.stl]
